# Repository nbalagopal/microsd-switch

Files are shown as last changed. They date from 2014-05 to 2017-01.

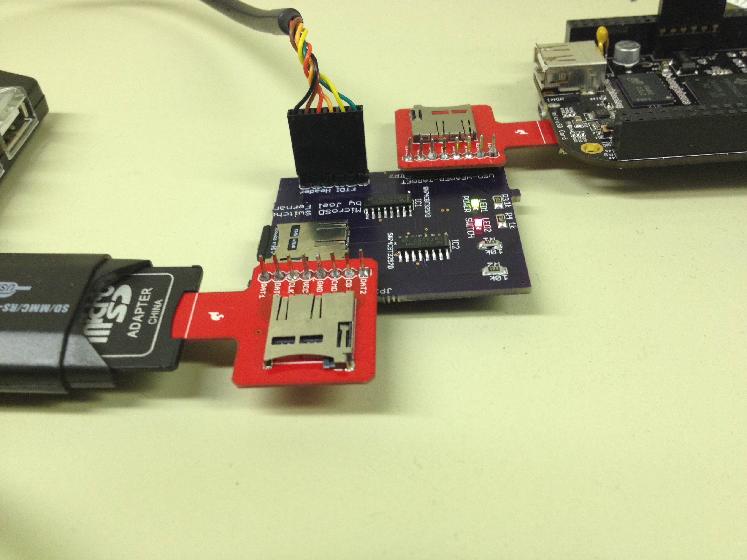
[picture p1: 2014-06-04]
board-pics/microsd-inaction/photo4.jpg

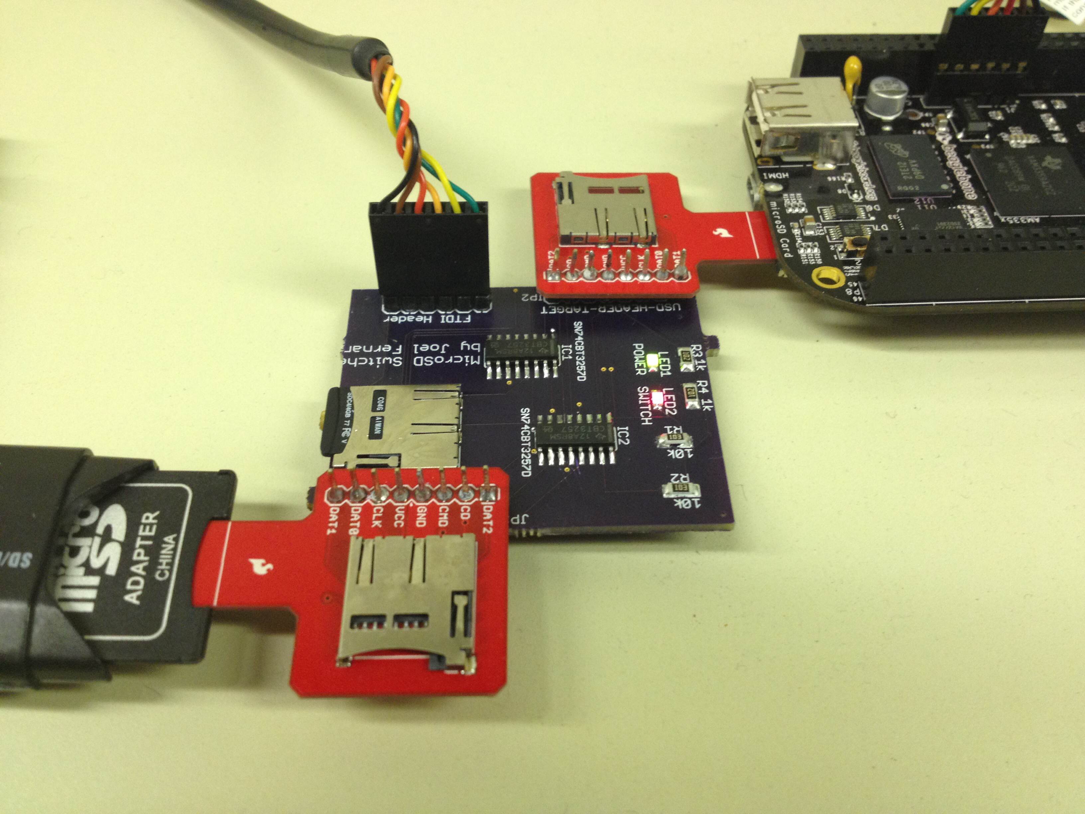
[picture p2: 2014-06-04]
board-pics/microsd-inaction/photo5.jpg

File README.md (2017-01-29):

# microSD card switcher
This board was created by [Joel Fernandez](http://www.linuxinternals.org/joel/) and a link to his blog post is given below
- [MicroSD card remote switch](http://www.linuxinternals.org/blog/2014/06/04/a-microsd-card-remote-switcher/)
- [Demo Video](https://youtu.be/StpIihVQ7oM)

## Features
- Connect one microSD card to 2 computers( or boards)
- Ensures that the sd card is connected to only one computer at a time
- Remotely control the switch over USB serial connection

## Parts list
- Circuit board - Make this yourself or use a vendor like [OSHPark](https://oshpark.com/), [Pcbway](http://www.pcbway.com/) etc
- [microSD card sniffer](https://www.sparkfun.com/products/9419) (2)
- [10k Resistors](https://www.sparkfun.com/products/11508) (2)
- [1k Resistors](https://www.sparkfun.com/products/13760) (2)
- [LEDs](https://www.sparkfun.com/products/12062) (2)
- [SN74CBT3257D - 4 bit FET Mux/DeMux](http://www.mouser.com/ProductDetail/Texas-Instruments/SN74CBT3257D) (2)
- [microSD slot](https://www.sparkfun.com/products/127) (1)
- [Male headers](https://www.sparkfun.com/products/116) (2)
- [FTDI Cable](https://www.sparkfun.com/products/9717)

## Building the switch program
### Using docker
If you have docker installed, just run the commands given below to get the built executable. The built executable works on 64 bit linux only.
    
    export MY_WORKSPACE=<you git workspace>
    chmod 777 $MY_WORKSPACE                                              # Need to do this so that root user in the container 
                                                                         # can write to the folder
    docker run -v $MY_WORKSPACE/sw:/workspace nbalagopal/microsd_switch  # 'switch' will be in your workspace.

### Directly on Linux
    # Install libftdi
    apt-get update -y
    apt-get install -y libftdi-dev libftdi1 libftdi1-dev libftdipp1-2v5 libftdipp1-dev
    
    # Install pkg-config
    apt-get install -y pkg-config
    
    # Verify libftdi installation
    pkg-config --cflags libftdi
    # Output:
    #  
    
    pkg-config --libs libftdi
    # Output: 
    #   -lftdi1
    
    # Build using gcc
    gcc $(pkg-config --cflags libftdi)  -o switch  switch.c  $(pkg-config --libs libftdi)

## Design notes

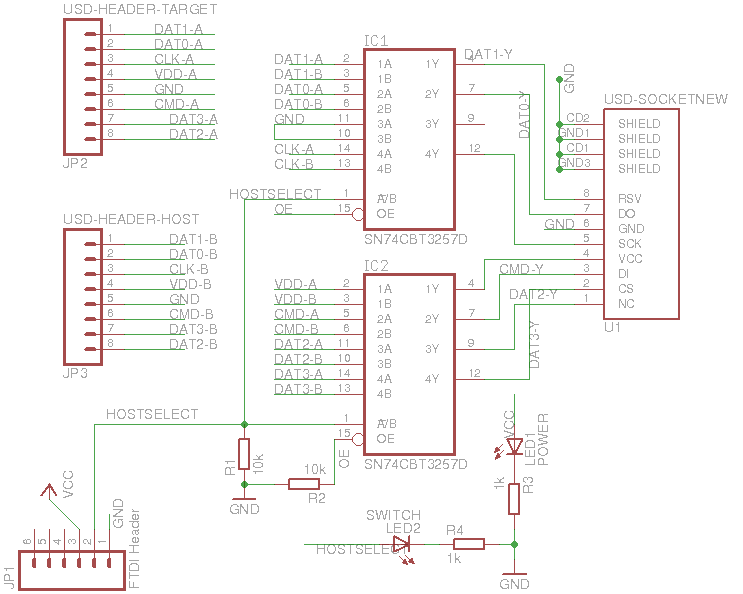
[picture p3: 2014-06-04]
board-pics/schematic.png

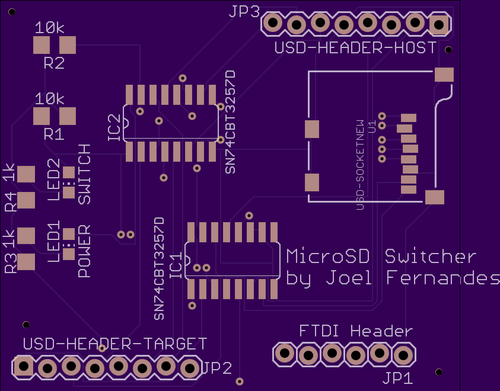
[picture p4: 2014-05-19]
board-pics/front.png

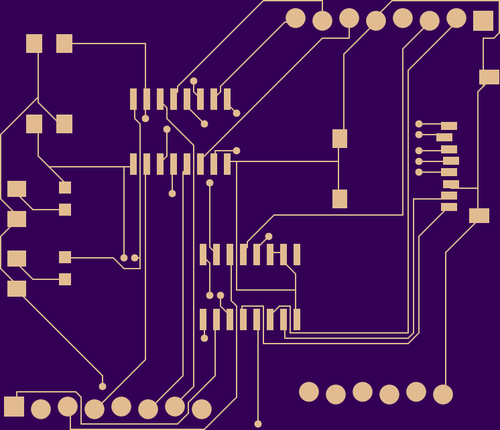
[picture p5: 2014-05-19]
board-pics/back.png

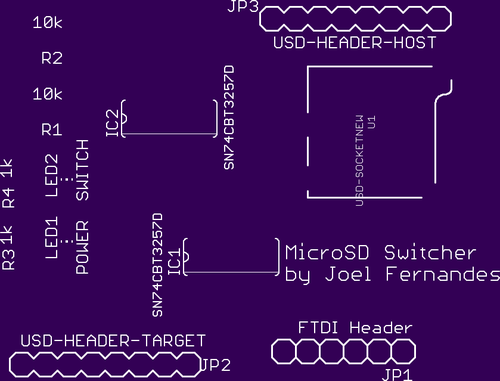
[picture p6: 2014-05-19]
board-pics/silkscreen.png

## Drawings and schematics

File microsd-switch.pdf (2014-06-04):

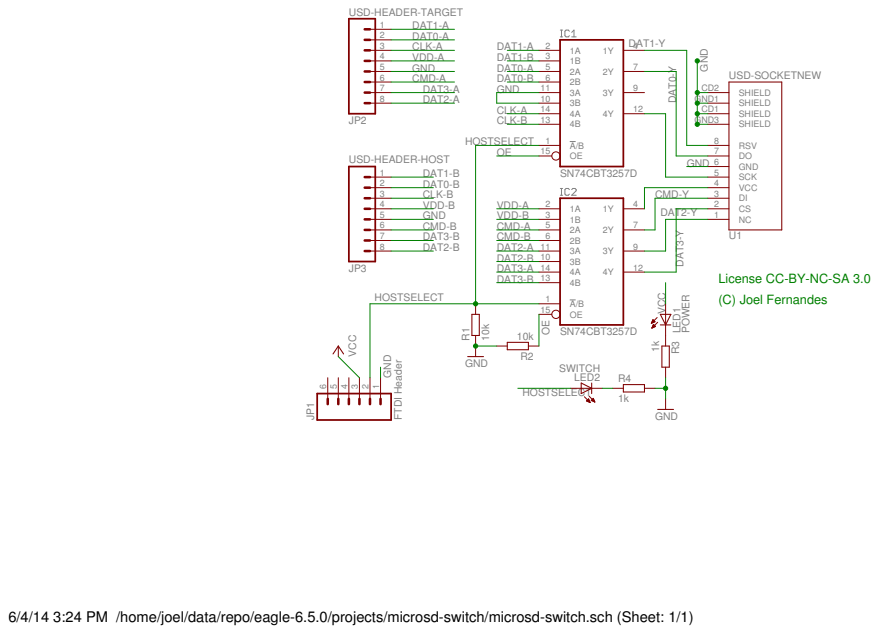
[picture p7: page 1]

License CC-BY-NC-SA 3.0
(C) Joel Fernandes

6/4/14 3:24 PM /home/joel/data/repo/eagle-6.5.0/projects/microsd-switch/microsd-switch.sch (Sheet: 1/1)

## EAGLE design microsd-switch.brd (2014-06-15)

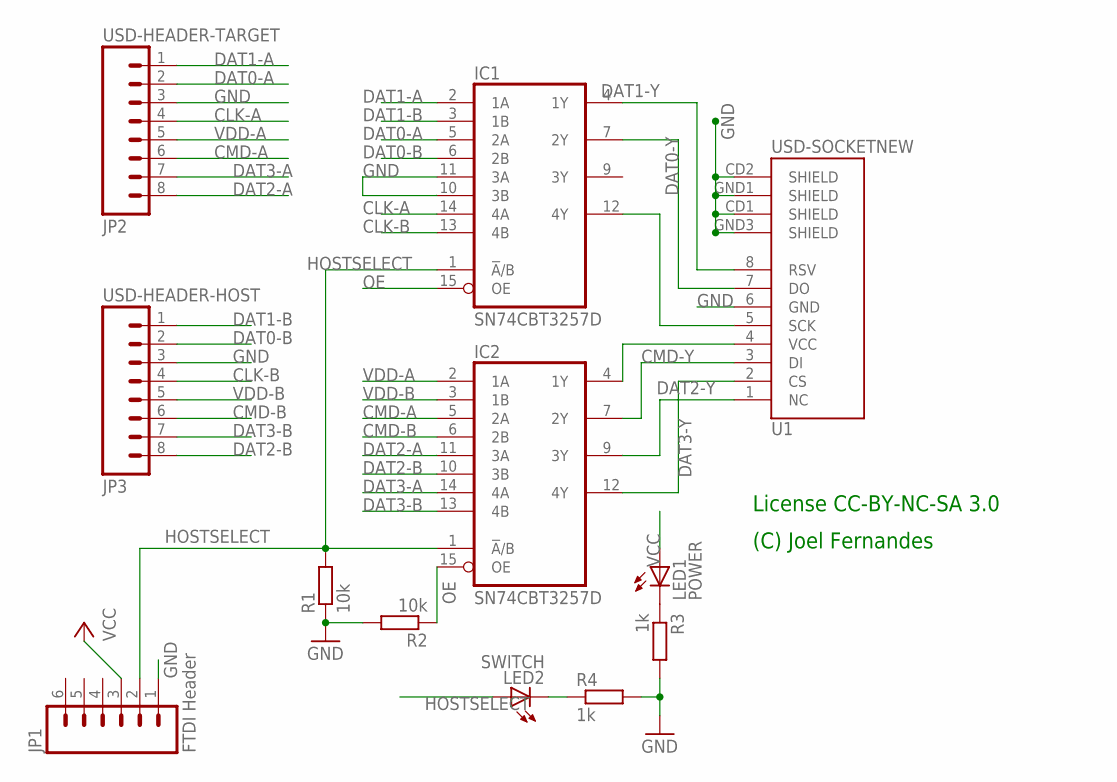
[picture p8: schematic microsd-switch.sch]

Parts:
IC1, IC2: SN74CBT3257D; SO16
JP1: FTDI Header; 1X06_LOCK
JP2: USD-HEADER-TARGET; 1X08_LOCK
JP3: USD-HEADER-HOST; 1X08_LOCK
LED1: POWER; CHIP-LED0805
LED2: SWITCH; CHIP-LED0805
R1, R2: 10k; R1206
R3, R4: 1k; R1206
U1: USD-SOCKETNEW; MICRO-SD-SOCKET-PP

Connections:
CLK-A: IC1.14 (4A), JP2.4
CLK-B: IC1.13 (4B), JP3.4
CLK-Y: IC1.12 (4Y), U1.5 (SCK)
CMD-A: IC2.5 (2A), JP2.6
CMD-B: IC2.6 (2B), JP3.6
CMD-Y: IC2.7 (2Y), U1.3 (DI)
DAT0-A: IC1.5 (2A), JP2.2
DAT0-B: IC1.6 (2B), JP3.2
DAT0-Y: IC1.7 (2Y), U1.7 (DO)
DAT1-A: IC1.2 (1A), JP2.1
DAT1-B: IC1.3 (1B), JP3.1
DAT1-Y: IC1.4 (1Y), U1.8 (RSV)
DAT2-A: IC2.11 (3A), JP2.8
DAT2-B: IC2.10 (3B), JP3.8
DAT2-Y: IC2.9 (3Y), U1.1 (NC)
DAT3-A: IC2.14 (4A), JP2.7
DAT3-B: IC2.13 (4B), JP3.7
DAT3-Y: IC2.12 (4Y), U1.2 (CS)
GND: IC1.8 (GND), IC1.10 (3B), IC1.11 (3A), IC2.8 (GND), JP1.1, JP2.3, JP3.3, R1.1, R2.2, R3.2, R4.2, U1.6 (GND), U1.CD1 (SHIELD), U1.CD2 (SHIELD), U1.GND1 (SHIELD), U1.GND3 (SHIELD)
HOSTSELECT: IC1.1 (!A!/B), IC2.1 (!A!/B), JP1.2, LED2.A, R1.2
unnamed: IC2.4 (1Y), U1.4 (VCC)
unnamed: LED1.C, R3.1
unnamed: LED2.C, R4.1
OE: IC1.15 (OE), IC2.15 (OE), R2.1
VCC: IC1.16 (VCC), IC2.16 (VCC), JP1.3, LED1.A
VDD-A: IC2.2 (1A), JP2.5
VDD-B: IC2.3 (1B), JP3.5

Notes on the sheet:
License CC-BY-NC-SA 3.0
(C) Joel Fernandes

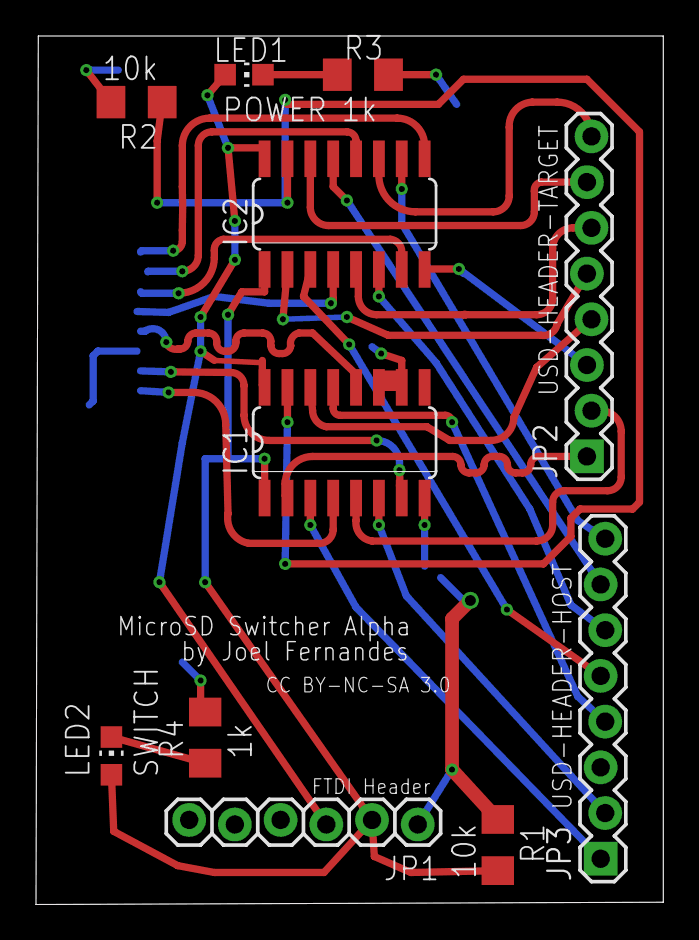
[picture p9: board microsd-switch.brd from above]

Board: 2 copper layers, 34.8 x 48.2 mm, 12 parts (1 on the bottom side), 27 nets.

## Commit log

2014-05-13 Basic schematic for microsd switcher
    [microsd-switch.sch]
2014-05-19 Update microsd-switcher project files
    Added pics, redesigned board, added a "legs" board.
    [microsd-legs.brd, microsd-legs.sch, microsd-switch.brd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]
2014-06-04 microsd-switch: switch: Add a program to program a board for host or target mode. Board is opened based on serial number.
2014-06-04 Add a script to simplify switching
    Usage: ./switch.sh <board-name> <on|off>
2014-06-04 Update license
    [microsd-switch.sch]
2014-06-04 schematic pdf
2014-06-05 Reduced uSD header connector size.
    [microsd-switch.brd, microsd-switch.sch]
2014-06-05 Revert "Reduced uSD header connector size."
    This reverts commit 164ab6429ac06b889099512f0f315f421e6ea5d6.
    [microsd-switch.brd, microsd-switch.sch]
2014-06-15 MicroSD Switch Rev Alpha released
    [microsd-switch.brd, microsd-switch.sch]
2017-01-20 Added microSD slot, headers and and FTDI cable to parts list

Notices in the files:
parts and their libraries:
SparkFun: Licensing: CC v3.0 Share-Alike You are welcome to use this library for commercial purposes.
